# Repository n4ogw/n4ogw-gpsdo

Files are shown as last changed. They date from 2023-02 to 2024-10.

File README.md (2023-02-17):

# N4OGW GPS Disciplined oscillator

This GPSDO is based on the Lars Walenius design posted on eevblog.com:

[https://www.eevblog.com/forum/projects/lars-diy-gpsdo-with-arduino-and-1ns-resolution-tic/](https://www.eevblog.com/forum/projects/lars-diy-gpsdo-with-arduino-and-1ns-resolution-tic/)

The code has been translated from the Arduino to PIC, a
PIC18F27Q84. Unlike the original design external ICs are not used to
divide the 10 MHz input or measure the phase difference between the 1
PPS signal and the input. Instead, PIC Configurable Logic Cell (CLC)
units are used to perform these functions. The only active devices
besides the PIC are an op amp to buffer the PWM output controlling the
OCXO, and an op amp buffer and inverter gate to buffer the sine wave
OCXO output.

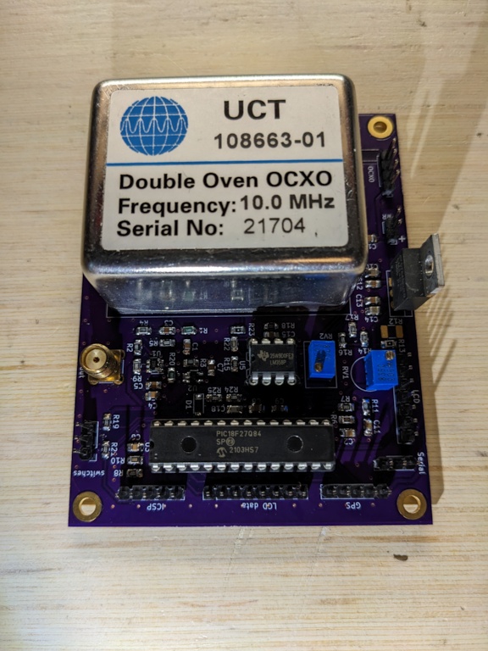
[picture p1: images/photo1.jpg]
GPSDO gpsdo pcb


## Features

* Time interval Counter (TIC) with range of 1000 ns and 0.24 ns/bit
resolution (12 bit ADC)
* 16 bit PWM output for controlling the OCXO
* Direct frequency count of 10 MHz input to monitor frequency
* serial connections for computer and GPS
* LCD display showing UTC time, 6 character grid square, PWM value, lock status, number of satellites, and frequency counter error

---

## Description of hardware

The OCXO is a UCT 108663 with sine wave output. This OCXO requires a
12 V supply. The voltage on the EFC pin for mine is about 5 V when
tuned for 10 MHZ. RV2 is adjusted to first set the frequency of the
OCXO close to 10 MHz. The OCXO is buffered with an ADA4851 op amp and
sent to a 74LVC1G14 inverter before going to the PIC input. The PIC is
a PIC18F27Q84. A PIC18F26Q84 should also work.

 The PIC PWM output is buffered by two op amp stages using an
LM358. The PIC PWM output is set up as a single 16 bit PWM, but a
second pin is available for combining two PWM outputs.  A voltage
regulator on the board generates 5 V for the PIC and the GPS module.
Resistor R17 is not used. The value of R12/R13 depend on whether
current limiting is needed for the LCD backlight; mine did not need
it, so I used a zero ohm jumper. R23 is also a zero ohm jumper.

---

## Description of PIC code

MPLab 6.05; XC8 2.40

### Pins

RA0 - RA7 : (outputs) data for 2x16 LCD in 8 bit mode

RB0 : LCD RS (output)

RB1 : ADC input; reads TIC voltage

RB2 : (input) 10 MHz in

RB3 : (output) TIC to 3.9 k resistor

RB4 : button 1 (input)

RB5 : button 2 (input)

RB6 : ICSP clock

RB7 : ICSP data

RC0 : (input) PPS in

RC1 : LCD E (output)

RC2 : (input) UART2 RX (GPS)

RC3 : (output) UART2 TX (GPS)

RC4 : unused; can be used as second PWM output combined with RC5

RC5 : (output) 16 bit PWM output

RC6 : (output) UART1 TX (computer)

RC7 : (input) UART1 RX  (computer)

### Frequency counter

The PIC Signal Measurement Timer (SMT) is used as a frequency counter
to directly count the 10 MHz input signal. The SMT is used in Counter
mode; the signal comes from SMT1SIGPPS connected to RB2 (10 MHz); the
window comes from SMT1WINPPS connected to RC0 (PPS). Period is set to
0xFFFFFF, pulse width acquisition interrupt is enabled.

In this mode, the interrupt function `SMT1_PW_ACQ_ISR` is called at
every PPS pulse. This function updates the total count and the error
compared to 10 MHz.

### TIC

In the original design, an external IC is used to divide the 10 MHz
down to 1 MHz to drive the TIC. This function is instead done using
PIC CLC gates, one D-type flip-flop (CLC2) configured as divide-by-two
followed by three JK flip-flops (CLC3, CLC5, CLC6) configured as
divide-by-five.  CLCIN2 is connected to RB2, 10 MHz in. The output of
CLC6 is the 1.0 MHz signal.

####CLC2 (divide by 2)

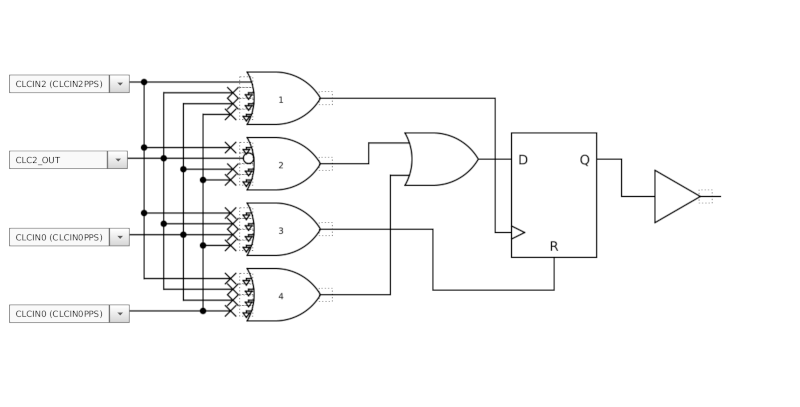
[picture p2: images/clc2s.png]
CLC2 clc2


####CLC3, CLC5, CLC6 (divide by 5)

####CLC3

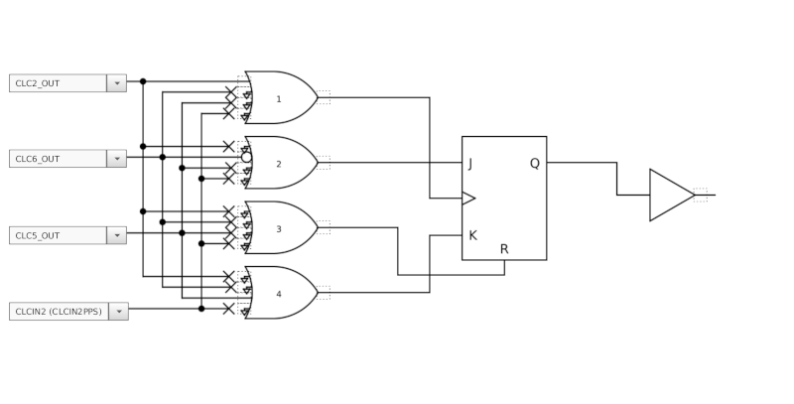
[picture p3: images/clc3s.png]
CLC3 clc3


####CLC5

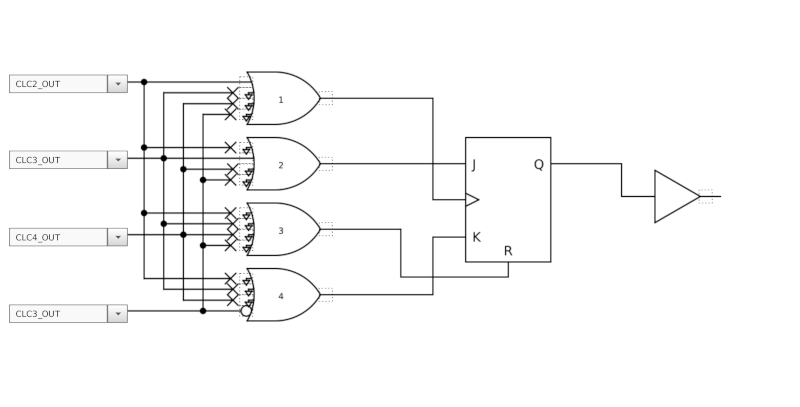
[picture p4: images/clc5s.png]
CLC5 clc5


####CLC6

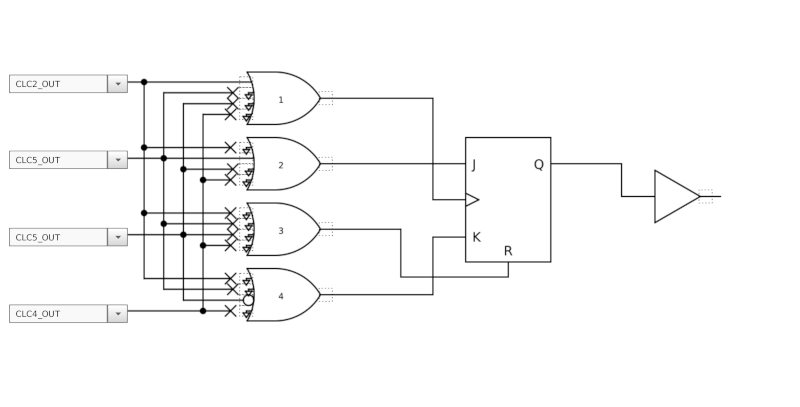
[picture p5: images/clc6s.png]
CLC6 clc6


####CLC1 and CLC7 (2 input D flip-flops with R)

Configured as the phase detector of the TIC. The inputs to CLC1 are
from CLC6 (1.0 MHz) and CLCIN3, which is mapped to RC0 (PPS). The
inputs to CLC7 are also PPS, and the output of CLC1. The output of
CLC7 drives the diode of the TIC circuit (RB3).

CLC1

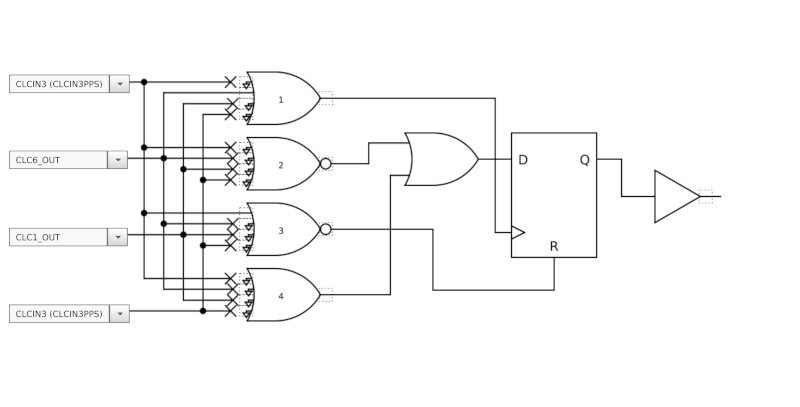
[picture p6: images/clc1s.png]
CLC1 clc1


CLC7

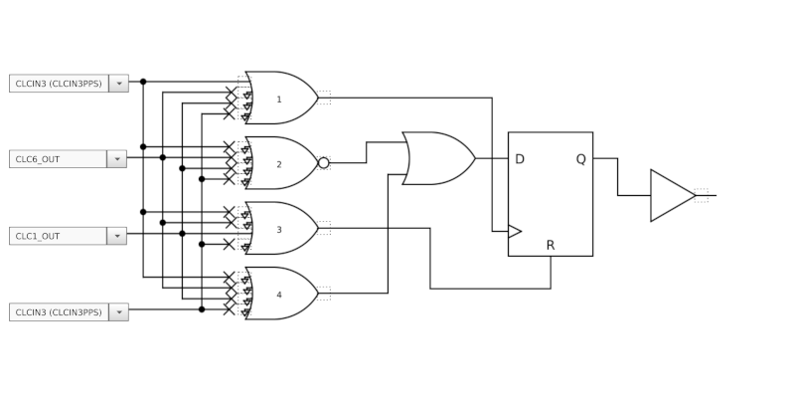
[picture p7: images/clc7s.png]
CLC7 clc7


The reference voltage of the ADC is set to 1.024 V using the FVR
voltage reference. The ADC is set to trigger on the output of
CLC7. The ADC interrupt is enabled; `adcInterrupt()` is the interrupt
function which reads the value of the TIC. With a 12-bit ADC this is
in the range 0-4095.

### Buttons

The two input buttons are debounced using CLC8 and timer 6. CLCIN6 and
CLCIN7 are mapped to the two button pins, RB4 and RB5. Timer 6
is set up in monostable mode with a period of 15 ms, with the output
of CLC8 as the reset source. The timer interrupt function is
`buttonInterrupt()`, which checks to see which button was pressed.

####CLC8

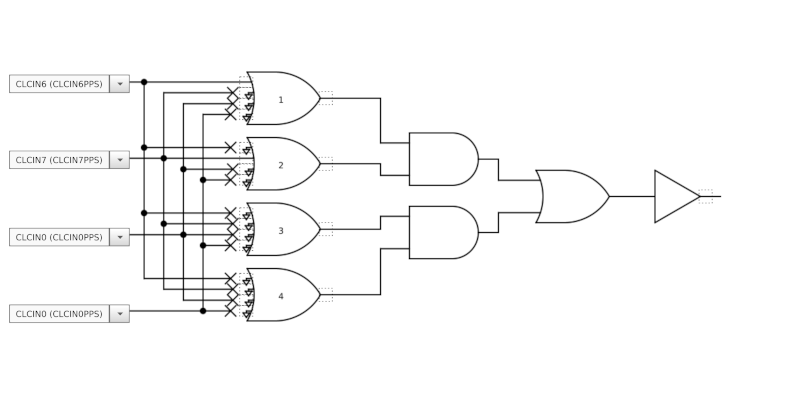
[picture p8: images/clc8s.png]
CLC8 clc8


####2x16 LCD

2x16 LCD library adopted from

[https://github.com/eziya/PIC18F_HD44780](https://github.com/eziya/PIC18F_HD44780)

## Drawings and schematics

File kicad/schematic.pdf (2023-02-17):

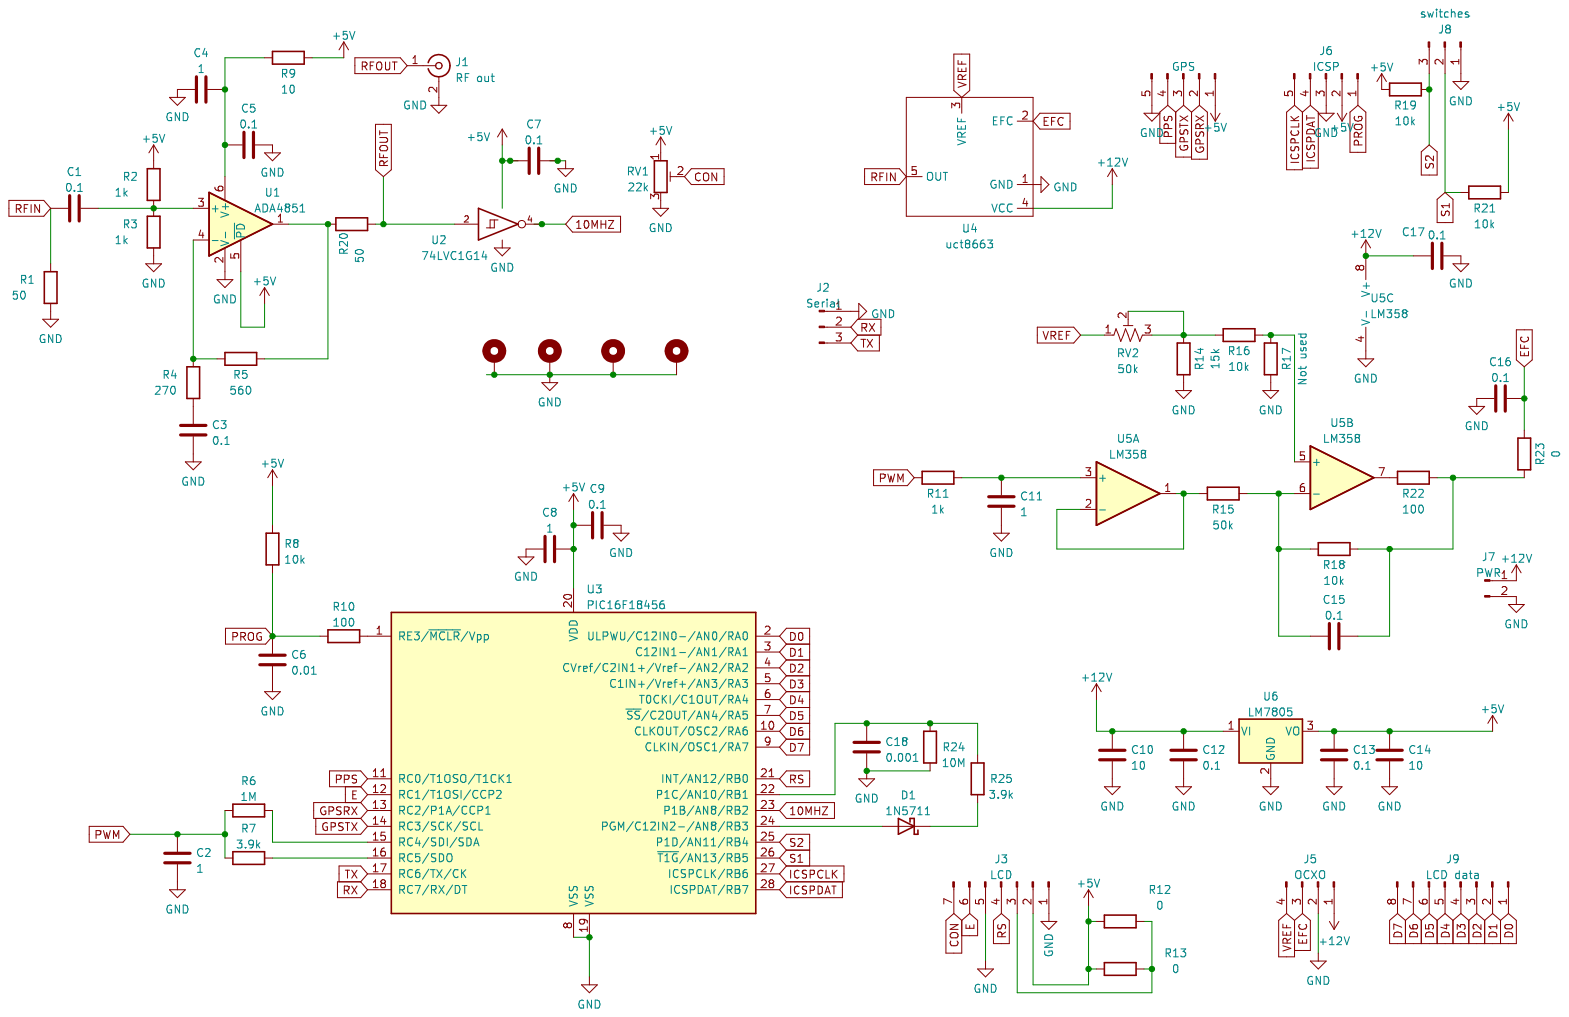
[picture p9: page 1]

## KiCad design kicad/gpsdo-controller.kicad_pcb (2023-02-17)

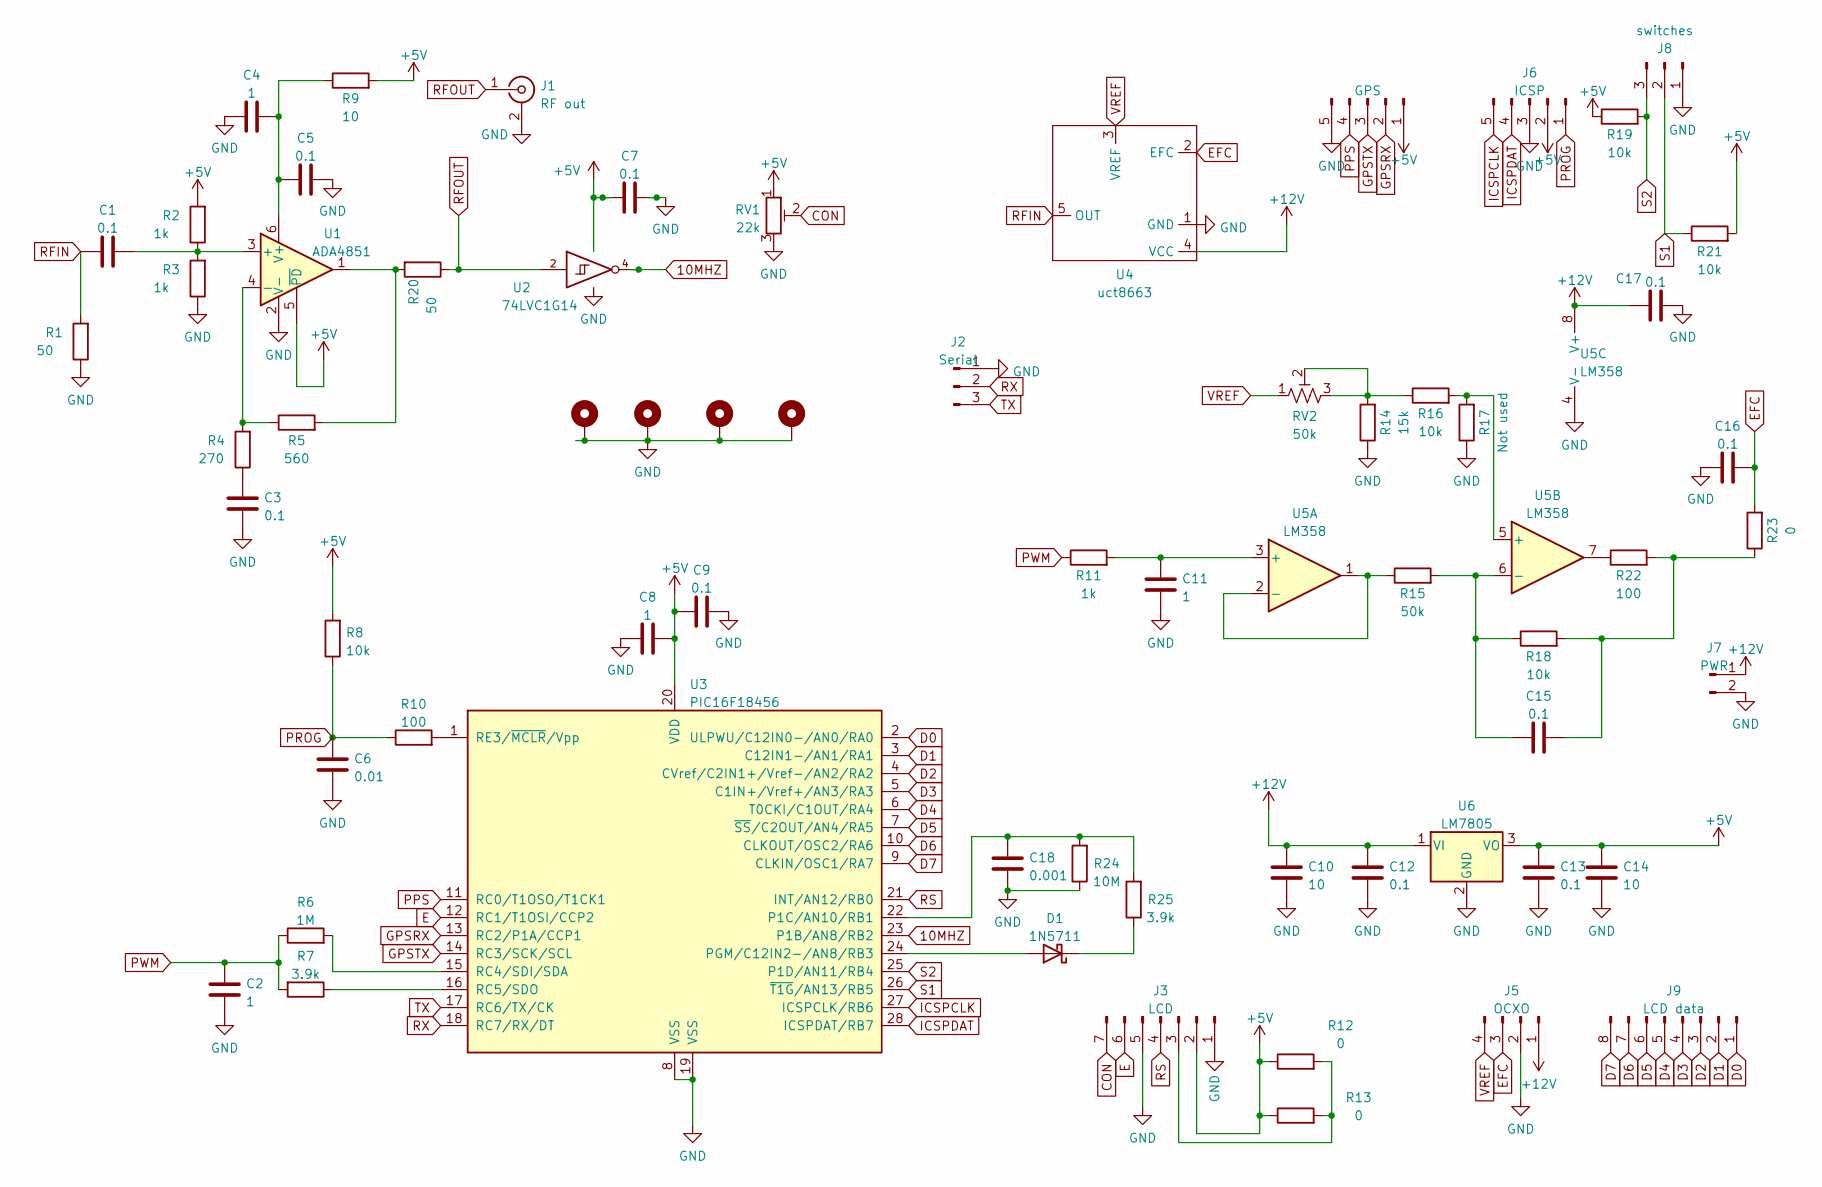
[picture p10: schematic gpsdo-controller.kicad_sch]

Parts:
C1, C3, C5, C7, C9, C12, C13, C15, C16, C17: 0.1; C_0805_2012Metric_Pad1.18x1.45mm_HandSolder
C2, C4, C8, C11: 1; C_0805_2012Metric_Pad1.18x1.45mm_HandSolder
C6: 0.01; C_0805_2012Metric_Pad1.18x1.45mm_HandSolder
C10, C14: 10; C_0805_2012Metric_Pad1.18x1.45mm_HandSolder
C18: 0.001; C_0805_2012Metric_Pad1.18x1.45mm_HandSolder
D1: 1N5711; D_SOD-123
H1, H2, H3, H4: GND; MountingHole_3.2mm_M3_DIN965_Pad
J1: RF out; SMA_Amphenol_901-144_Vertical
J2: Serial; PinHeader_1x03_P2.54mm_Vertical
J3: LCD; PinHeader_1x07_P2.54mm_Vertical
J4: GPS; PinHeader_1x05_P2.54mm_Vertical
J5: OCXO; PinHeader_1x04_P2.54mm_Vertical
J6: ICSP; PinHeader_1x05_P2.54mm_Vertical
J7: PWR; PinHeader_1x02_P2.54mm_Vertical
J8: switches; PinHeader_1x03_P2.54mm_Vertical
J9: LCD data; PinHeader_1x08_P2.54mm_Vertical
R1, R20: 50; R_0805_2012Metric_Pad1.20x1.40mm_HandSolder
R2, R3, R11: 1k; R_0805_2012Metric_Pad1.20x1.40mm_HandSolder
R4: 270; R_0805_2012Metric_Pad1.20x1.40mm_HandSolder
R5: 560; R_0805_2012Metric_Pad1.20x1.40mm_HandSolder
R6: 1M; R_0805_2012Metric_Pad1.20x1.40mm_HandSolder
R7, R25: 3.9k; R_0805_2012Metric_Pad1.20x1.40mm_HandSolder
R8, R16, R18, R19, R21: 10k; R_0805_2012Metric_Pad1.20x1.40mm_HandSolder
R9: 10; R_0805_2012Metric_Pad1.20x1.40mm_HandSolder
R10, R22: 100; R_0805_2012Metric_Pad1.20x1.40mm_HandSolder
R12: 0; R_1210_3225Metric_Pad1.30x2.65mm_HandSolder
R13, R23: 0; R_0805_2012Metric_Pad1.20x1.40mm_HandSolder
R14: 15k; R_0805_2012Metric_Pad1.20x1.40mm_HandSolder
R15: 50k; R_0805_2012Metric_Pad1.20x1.40mm_HandSolder
R17: Not used; R_0805_2012Metric_Pad1.20x1.40mm_HandSolder
R24: 10M; R_0805_2012Metric_Pad1.20x1.40mm_HandSolder
RV1: 22k; Potentiometer_Vishay_T7-YA_Single_Vertical
RV2: 50k; Potentiometer_Bourns_3299Y_Vertical
U1: ADA4851; SOT-23-6
U2: 74LVC1G14; SOT-353_SC-70-5_Handsoldering
U3: PIC16F18456; DIP-28_W7.62mm
U4: uct8663
U5: LM358; DIP-8_W7.62mm
U6: LM7805; TO-220-3_Vertical

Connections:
10MHZ: U2.4, U3.23 (P1B/AN8/RB2)
+5V: C7.1, C8.2, C9.1, C13.2, C14.2, J3.2, J4.1, J6.2, R2.2, R8.2, R9.2, R12.1, R13.1, R19.1, R21.2, RV1.1, U1.5 (~PD), U2.5 (VCC), U3.20 (VDD), U6.3 (VO)
+12V: C10.2, C12.2, C17.1, J5.1, J7.1, U4.4 (VCC), U5.8 (V+), U6.1 (VI)
CON: J3.7, RV1.2
D0: J9.1, U3.2 (ULPWU/C12IN0-/AN0/RA0)
D1: J9.2, U3.3 (C12IN1-/AN1/RA1)
D2: J9.3, U3.4 (CVref/C2IN1+/Vref-/AN2/RA2)
D3: J9.4, U3.5 (C1IN+/Vref+/AN3/RA3)
D4: J9.5, U3.6 (T0CKI/C1OUT/RA4)
D5: J9.6, U3.7 (~SS/C2OUT/AN4/RA5)
D6: J9.7, U3.10 (CLKOUT/OSC2/RA6)
D7: J9.8, U3.9 (CLKIN/OSC1/RA7)
E: J3.6, U3.12 (RC1/T1OSI/CCP2)
EFC: C16.1, J5.3, R23.2, U4.2 (EFC)
GND: C2.1, C3.1, C4.1, C5.2, C6.1, C7.2, C8.1, C9.2, C10.1, C11.1, C12.1, C13.1, C14.1, C16.2, C17.2, C18.1, H1.1, H2.1, H3.1, H4.1, J1.2 (Ext), J2.1, J3.1, J3.5, J4.5, J5.2, J6.3, J7.2, J8.1, R1.1, R3.1, R14.1, R17.1, R24.1, RV1.3, U1.2 (V-), U2.3 (GND), U3.8 (VSS), U3.19 (VSS), U4.1 (GND), U5.4 (V-), U6.2 (GND)
GPSRX: J4.2, U3.13 (RC2/P1A/CCP1)
GPSTX: J4.3, U3.14 (RC3/SCK/SCL)
ICSPCLK: J6.5, U3.27 (ICSPCLK/RB6)
ICSPDAT: J6.4, U3.28 (ICSPDAT/RB7)
unnamed: C1.2, R2.1, R3.2, U1.3 (+)
unnamed: C3.2, R4.1
unnamed: C4.2, C5.1, R9.1, U1.6 (V+)
unnamed: C11.2, R11.2, U5.3 (+)
unnamed: C15.1, R15.2, R18.1, U5.6 (-)
unnamed: C15.2, R18.2, R22.2, R23.1
unnamed: C18.2, R24.2, R25.2, U3.22 (P1C/AN10/RB1)
unnamed: D1.1 (K), R25.1
unnamed: D1.2 (A), U3.24 (PGM/C12IN2-/AN8/RB3)
unnamed: J3.3, R12.2, R13.2
unnamed: R4.2, R5.1, U1.4 (-)
unnamed: R6.2, U3.15 (RC4/SDI/SDA)
unnamed: R7.1, U3.16 (RC5/SDO)
unnamed: R10.2, U3.1 (RE3/~MCLR/Vpp)
unnamed: R14.2, R16.1, RV2.2, RV2.3
unnamed: R15.1, U5.1, U5.2 (-)
unnamed: R16.2, R17.2, U5.5 (+)
unnamed: R5.2, R20.2, U1.1
unnamed: R22.1, U5.7
PPS: J4.4, U3.11 (RC0/T1OSO/T1CK1)
PROG: C6.2, J6.1, R8.1, R10.1
PWM: C2.2, R6.1, R7.2, R11.1
RFIN: C1.1, R1.2, U4.5 (OUT)
RFOUT: J1.1 (In), R20.1, U2.2
RS: J3.4, U3.21 (INT/AN12/RB0)
RX: J2.2, U3.18 (RC7/RX/DT)
S1: J8.2, R21.1, U3.26 (~T1G/AN13/RB5)
S2: J8.3, R19.2, U3.25 (P1D/AN11/RB4)
TX: J2.3, U3.17 (RC6/TX/CK)
VREF: J5.4, RV2.1, U4.3 (VREF)

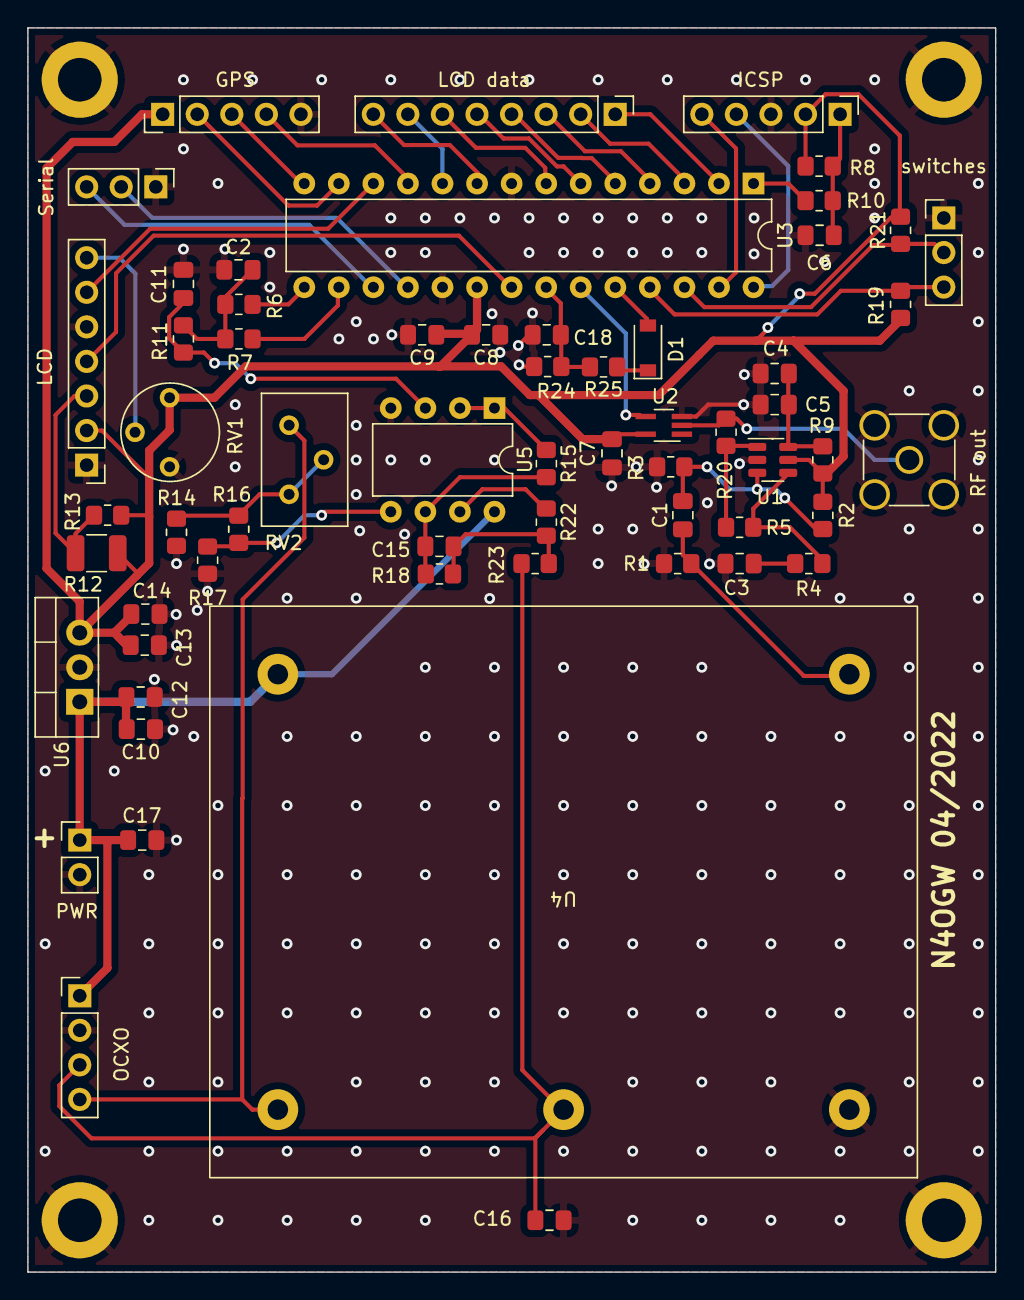
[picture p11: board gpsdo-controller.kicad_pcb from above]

Board: 2 copper layers, 71.1 x 91.4 mm, 65 parts (0 on the bottom side), 49 nets.

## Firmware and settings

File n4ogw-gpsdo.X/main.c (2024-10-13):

/*
 GPSDO controller based on "Lars GPSDO" design using PIC18F27Q84

 R. Torsten Clay N4OGW
  
 for board version 2
 05/20/2023

  1. Counts 10 MHz directly using PIC SMT
  2. Divides 10 MHz down to 1 MHz; measures phase difference between 1 MHz and
     GPS PPS signal

  Frequency division and phase difference measurement are done using PIC
  CLC gates instead of by external hardware:
 
  -two CLC D flip-flops are used (CLC1 and CLC7) for the phase detector
  -CLC2, CLC3, CLC5, CLC6 are configured as a divide-by-10 counter
      -> these together create a 1 MHz signal from the OCXO (duty
      cycle is not 50%)
  -CLC8 and timer6 are used to de-bounce buttons
  -SMT is used to count 10 MHz directly (24 bit counter), gated by PPS
  -16 bit PWM generated directly instead of combining two 8-bit PWMs
 
  Pin connections:
 
  RA0 - RA7 : outputs; data for 2x16 LCD in 8 bit mode
  RB0 : LCD RS
  RB1 : ADC input; reads TIC voltage
  RB2 : 10 MHz in
  RB3 : TIC output; to 3.9 k resistor
  RB4 : button 1
  RB5 : button 2
  RB6 : ICSP clock
  RB7 : ICSP data
  RC0 : pps in
  RC1 : LCD E
  RC2 : uart2 rx (gps)
  RC3 : uart2 tx (gps)
  RC4 unused : can be 2nd pwm output
  RC5 : 16 bit PWM out
  RC6 : uart1 tx (computer)
  RC7 : uart1 rx (computer)
 */

// suppress MCC "function never called" messages
#pragma warning disable 520
#pragma warning disable 2053

#include <stdio.h>
#include <stdlib.h>
#include <stdbool.h>
#include "defines.h"
#include "mcc_generated_files/pin_manager.h"
#include "mcc_generated_files/mcc.h"
#include "mcc_generated_files/pwm1_16bit.h"
#include "xlcd.h"

void adcInterrupt();
void buttonInterrupt(void);
void button2Func(void);
void calculation(void);
void checkButtons(void);
void counterSetup(void);
void counterUpdate(void);
void getCommand(void);
void gpsConfig(void);
void gpsExtraOff(void);
void gpsExtraOn(void);
void gpsParse(void);
void gpsRead(void);
inline uint8_t highByte(uint16_t x);
inline uint8_t lowByte(uint16_t x);
void lcdSetup(void);
void lcdUpdate(void);
long parseInt(void);
void printDataToSerial(void);
void printHeader1_ToSerial(void);
void printHeader2_ToSerial(void);
void printHeader3_ToSerial(void);
void setup(void);
void setScreen(screenType newScreen);

uint16_t warmUpTime = 300; // 300 gives five minutes hold during eg OCXO or Rb warmup. Set to eg 3 for VCTCXO
int32_t dacValueOut = 32768; // 16bit PWM-DAC setvalue=startvalue Max 65535 (if nothing stored in the EEPROM)
int32_t dacValue; // this is also same as "DACvalueOld" Note: is "0-65535" * timeconst

volatile uint16_t TIC_Value; // analog read 0  - time value. About 0.25ns per bit with 3.9kohm+1nF
uint16_t TIC_ValueCopy;
uint16_t TIC_ValueOld; // old not filtered TIC_value

int32_t TIC_ValueFiltered; // pre-filtered TIC value
int32_t TIC_ValueFilteredOld; // old filtered value
int32_t TIC_ValueFilteredForPPS_lock; // pre-filtered value just for PPS lock
const uint8_t lockFilterConst = 16;

volatile uint32_t timer1CounterValue; // counts 10 MHz clock directly
uint32_t timer1CounterValueOld;

long timer_us; // timer1 value in microseconds offset from 1pps
long timer_us_old; // used for diff_ns
// timer_us is calculated, but not used for dac correction in this
// version of code
long diff_ns; // difference between old and new TIC_Value
long diff_ns_ForPPS_lock; // pre-filtered value just for PPS lock

long timeConst = 128; // Time constant in seconds
long timeConstOld = 128; // old Time constant
int filterDiv = 2; // filterConst = timeConst / filterDiv
long filterConst = 64; // pre-filter time const in secs (TIC-filtering)
long filterConstOld = 64; // old Filter time constant

float I_term; //for PI-loop
float P_term;
long I_term_long;
float I_term_remain;

long gain = 275;

// Arduino TIC calculation:
// VCO freq DAC bits per TIC bit (65536/VCOrange in ppb (eg. with 1nS/bit and 100ppb DACrange gives gain=655))
//
// PIC TIC calculation:
//     12 bit ADC, 1 MHz : 1000ns/4096 = 0.24 ns/bit, so now gain 
//     is 0.24*65536/VCO_ppb

float damping = 3.0; // Damping in loop

unsigned long time; //seconds since start
unsigned long timeOld; //last seconds since start
volatile bool ADCFlag = false; // set true every time ADC reads TIC
volatile bool SMTFlag = false;

#ifdef VENUS838T
extern uint8_t venusElevMask;
extern uint8_t venusMode;
extern uint8_t venusSurveyCnt[8];
extern void setVenusElevMask(uint8_t x);
#endif

float quantErr;
bool quantErrFlag;      // correct for gps time quantization error if available
int lockPPSlimit = 200; // if TIC filtered for PPS within +- this for lockPSfactor * timeConst = PPSlocked
                        // ~ 100 per 1000 of ADC range
int lockPPSfactor = 5;  // see above
unsigned long lockPPScounter; // counter for PPSlocked
bool PPSlocked; // prints 0 or 1

int i; // counter for 300secs before storing temp and dac readings average
int j; // counter for stored 300sec readings
int k; // counter for stored 3hour readings
unsigned int StoreTIC_A[NSTORE]; //300sec storage
unsigned int StoreDAC_A[NSTORE];
long sumTIC;
long sumTIC2;
long sumTemp;
long sumTemp2;
unsigned long sumDAC;
unsigned long sumDAC2;
unsigned int totalTime3h; // counter for power-up time updated every third hour

unsigned int ID_Number;

bool lessInfoDisplayed;
bool nsDisplayedDecimals;

SerialModes serialMode = on;
unsigned int holdValue; //DAC value for Hold mode
Modes opMode; //operating mode
Modes newMode; // used to reset timer_us when run is set and at to many missing PPS

// for TIC linearization
// RTC: best parameters found using a PicDiv
float TICmin = 60.0;
float TICmax = 4036.0;
long TIC_Offset = 2048; // ADC value for Reference time. This is chosen in the middle point of
// the ADC range.
float x3 = 0.03;
float x2 = 0.08;
float x1;
float TIC_Scaled;
float TIC_ValueCorr;
float TIC_ValueCorrOld;
float TIC_ValueCorrOffset;

const int dacSign = -1; // sign of OCXO EFC correction. +1 in original code, -1 if tuning is inverted
volatile uint16_t cnt; // counts measurements 65535 is max
volatile uint32_t elapsed;
volatile int totalErr; // total error count
uint16_t nCnt = 1000; // frequency counter gate time in seconds
int lostPPSCount;
const uint8_t nScreen = 5;
screenType screen;
uint8_t gpsTime[9]; // latest time from GPS
char errStr[8]; // displayed frequency error
char pwmStr[6]; // displayed pwm setting
uint8_t gpsSentence[256]; // one GPS NMEA line
uint8_t grid[7]; // 6 character grid square from GPS
uint8_t nsat[3]; // number of satellites received by GPS
uint8_t gpsCnt; // counts up to 256 to read one GPS line
uint8_t gpsCheckCnt; // counter for gps checksum
uint16_t gridCnt; // counter to periodically update grid 
const uint16_t gridFreq = 3000; // time in seconds to recheck grid square

volatile uint8_t button1State; // button 1. 0=not pushed 1=pushed
volatile uint8_t button2State; // button 2. 0=not pushed 1=pushed

void main(void) {
    // Initialize the device
    SYSTEM_Initialize();

    ADC_SetADIInterruptHandler(adcInterrupt);
    // If using interrupts in PIC18 High/Low Priority Mode you need to enable the Global High and Low Interrupts
    // If using interrupts in PIC Mid-Range Compatibility Mode you need to enable the Global Interrupts
    // Use the following macros to:

    // Enable the Global Interrupts
    INTERRUPT_GlobalInterruptEnable();

    // Disable the Global Interrupts
    //INTERRUPT_GlobalInterruptDisable();

    __delay_ms(1000);
    setup();
    counterSetup();
    lcdSetup();
    PWM1_16BIT_Enable();
    SMT1_DataAcquisitionEnable();
    
    INTERRUPT_GlobalInterruptEnable();
    
    while (1) {
        if (SMTFlag == true) {
            if (cnt >= nCnt) {
                counterUpdate();
            }
            SMTFlag = false;
        }
        if (ADCFlag == true) {
            calculation();
            ADCFlag = false;
            if (serialMode == on) printDataToSerial();
            lcdUpdate();
        }
        if (serialMode == on || serialMode == gps) getCommand();
        gpsRead();
        checkButtons();
    }
}

/* 
 Interrupt triggered when ADC conversion of TIC value is
 ready. This should always come after the SMT timer
 interrupt
 
 MCC generated function clears the interrupt bit
 */
void adcInterrupt() {
    TIC_Value = (uint16_t)((ADRESH << 8) + ADRESL);
    ADCFlag = true;
}

/*
   Interrupt triggered when SMT finishes measurement
   this is triggered every PPS pulse
 */
void SMT1_PW_ACQ_ISR(void) {
    timer1CounterValueOld = timer1CounterValue;
    timer1CounterValue = SMT1CPW;

    // handle counter rollover (SMT is 24 bit counter, value is held as
    // 32-bit unsigned)
    elapsed = timer1CounterValue - timer1CounterValueOld;
    if (timer1CounterValue < timer1CounterValueOld) {
      elapsed += 0xff000000;
    }
   
    totalErr += (elapsed - FREQ);
    cnt++;

    SMTFlag = true;
    PIR1bits.SMT1PWAIF = 0;
}

/*
  Update frequency counter. This does a simple count
  of the frequency over nCnt seconds.
 */
void counterUpdate(void) {

    // first count is invalid since timer1CounterValueOld undefined
    if (time < (warmUpTime + nCnt)) {
        cnt = 0;
        totalErr = 0;
        return;
    }
    // average error in Hz
    float err = totalErr / (float) nCnt;

    // construct frequency error string
    switch (nCnt) {
        case 10:
            sprintf(errStr, "%3.1f    ", err);
            break;
        case 100:
            sprintf(errStr, "%4.2f   ", err);
            break;
        case 1000:
            sprintf(errStr, "%5.3f  ", err);
            break;
        default:
            sprintf(errStr, "%6.4f ", err);
            break;
    }
    // replace leading zero with sign or blank
    // for zero
    if (totalErr == 0) {
        errStr[0] = 0x20; //' '
    } else if (totalErr > 0) {
        errStr[0] = 0x2b; //'+'
    } else {
        errStr[0] = 0x2d; //'-'
    }
    if (screen == home) {
        CLCD_SetPos(0, 0);
        CLCD_PutS((char *) errStr);
    }
    if (serialMode == on) printf("FREQ COUNTER ERROR = %f Hz\r\n", err);
    cnt = 0;
    totalErr = 0;

}

void calculation(void) {
    if ((timer1CounterValue - timer1CounterValueOld) == 0) {
        if (serialMode == on) printf("No PPS\r\n");
        lostPPSCount++;
        if (lostPPSCount > 20) {
            newMode = run;
        }
        if (lostPPSCount > 200) {
            lockPPScounter = 0;
        }

    } else {
        lostPPSCount = 0;
    }

    // TIC linearization
    TIC_ValueCopy = TIC_Value;
    x1 = (float) 1.0 - x3 - x2;
    TIC_Scaled = ((float) TIC_Offset - TICmin) / (TICmax - TICmin)*1000; // Scaling for TIC_Offset
    TIC_ValueCorrOffset = TIC_Scaled * x1 + TIC_Scaled * TIC_Scaled * x2 / (float) 1000.0 +
            TIC_Scaled * TIC_Scaled * TIC_Scaled * x3 / (float) 1000000.0;

    TIC_Scaled = ((float) TIC_ValueCopy - TICmin) / (TICmax - TICmin)*1000; // Scaling for TIC_Value
    TIC_ValueCorr = TIC_Scaled * x1 + TIC_Scaled * TIC_Scaled * x2 / (float) 1000.0 +
            TIC_Scaled * TIC_Scaled * TIC_Scaled * x3 / (float) 1000000.0;

    if (quantErrFlag) TIC_ValueCorr += quantErr;

    // timer_us
    // dt is in units of 10^-7 = 0.1 microseconds = 100 ns
    long dt = elapsed - FREQ;

    // timer_us is in microseconds
    if (quantErrFlag) {
        timer_us = timer_us - (dt * 100
                + (TIC_ValueCopy + (int) quantErr - TIC_ValueOld)*1000 / 4096) / 1000;
    } else {
        timer_us = timer_us - (dt * 100
                + (TIC_ValueCopy - TIC_ValueOld)*1000 / 4096) / 1000;
    }

    if (newMode == run) {
        // reset timer_us if change from hold mode to run mode
        timer_us = 0;
        timer_us_old = 0;
        TIC_ValueFilteredOld = TIC_Offset * filterConst;
        newMode = hold;
    }

    // reset in the beginning and end of warmup 
    if (time < 3 || (time > (warmUpTime - 1) && time < (warmUpTime + 1))) {
        timer_us = 0;
    }

    if ((labs(timer_us) - 2) > timeConst * 65536 / gain / 1000 && opMode == run && time > warmUpTime) {
        timer_us = 0;
        timer_us_old = 0;
        TIC_ValueFilteredOld = TIC_Offset * filterConst;
    }

    // Diff_ns
    if (TIC_ValueCorr > TIC_ValueCorrOld) {
        // = Frequency in ppb if updated every second! Note: TIC linearized
        diff_ns = (timer_us - timer_us_old)*1000 +
                (long) (TIC_ValueCorr - TIC_ValueCorrOld + 0.5);
    } else {
        diff_ns = (timer_us - timer_us_old)*1000 +
                (long) (TIC_ValueCorr - TIC_ValueCorrOld - 0.5);
    }

    // time - seconds since start
    if ((timer1CounterValue - timer1CounterValueOld) != 0) time++;

    ////// PPS locked

    // Low Pass Filter of TIC_Value for PPS lock  
    // /16 is used as 500ns error and /16 is about 30ns that seems reasonable
    TIC_ValueFilteredForPPS_lock = TIC_ValueFilteredForPPS_lock + (TIC_ValueCopy * lockFilterConst - TIC_ValueFilteredForPPS_lock) / lockFilterConst;

    // Low Pass Filter of diff_ns for PPS lock                                                                             
    diff_ns_ForPPS_lock = diff_ns_ForPPS_lock + (diff_ns * lockFilterConst - diff_ns_ForPPS_lock) / lockFilterConst;

    lockPPScounter = lockPPScounter + 1;
    if (labs(TIC_ValueFilteredForPPS_lock / lockFilterConst - TIC_Offset) > lockPPSlimit) {
        lockPPScounter = 0;
    }
    // if freq more than 20ppb wrong (had to add this to avoid certain combinations not covered by above)
    if (labs(diff_ns_ForPPS_lock / lockFilterConst) > 20) {
        lockPPScounter = 0;
    }
    
    if (lockPPScounter > timeConst * lockPPSfactor) {
        PPSlocked = 1;
        if (screen == home) {
            CLCD_SetPos(0, 12);
            CLCD_PutS("L");
        }
    } else {
        PPSlocked = 0;
        if (screen == home) {
            CLCD_SetPos(0, 12);
            if (time > warmUpTime) {
                CLCD_PutS(" ");
            } else {
                CLCD_PutS("W");
            }
        }
    }
    if (screen == home) {
        switch (time % 2) {
            case 0:
                CLCD_SetPos(0, 11);
                CLCD_PutS("|");
                break;
            case 1:
                CLCD_SetPos(0, 11);
                CLCD_PutS("-");
                break;
        }
    }
     
    // set filter constant
    filterConst = timeConst / filterDiv;
    if (filterConst < 1) {
        filterConst = 1;
    } else if (filterConst > 1024) {
        filterConst = 1024;
    }
    if (PPSlocked == 0 || opMode == hold) filterConst = 1;

    // recalculation of value  
    if (timeConst != timeConstOld) {
        dacValue = dacValue / timeConstOld * timeConst;
    }

    if (filterConst != filterConstOld) {
        TIC_ValueFilteredOld = TIC_ValueFilteredOld / filterConstOld * filterConst;
        TIC_ValueFiltered = TIC_ValueFiltered / filterConstOld * filterConst;
    }

    // Low Pass Filter for TICvalue (Phase Error)
    // Remember that TIC_ValueFiltered is multiplied by filterConst

    // Don´t update if outlier. Accepts diff_ns less than same ns as vco range in ppb + 200ns
    // First check to avoid overflow in next calculation (also max VCO range is about 6500ns/s)

    // RTC changes: ignore large TIC changes if locked.
    if (abs(diff_ns < 260))
        // if (PPSlocked==0 || (PPSlocked==1 && diff_ns < 260))
    {
        if (labs(diff_ns * gain) < (65535 + 200 * gain)) {
            if (quantErrFlag) {
                TIC_ValueFiltered = TIC_ValueFiltered +
                        ((timer_us * 1000 +
                        TIC_ValueCopy + (int) quantErr) * filterConst - TIC_ValueFiltered + (filterConst / 2)) / filterConst;
            } else {
                TIC_ValueFiltered = TIC_ValueFiltered +
                        ((timer_us * 1000 +
                        TIC_ValueCopy) * filterConst - TIC_ValueFiltered + (filterConst / 2)) / filterConst;
            }
        }
    }

    // Don't change DAC-value during warm-up time or if in hold mode
    if (time > (warmUpTime + 1) && opMode == run) {
        ////// PI-loop ///////
        // remember /timeConst is done before dacValue is sent out
        P_term = (TIC_ValueFiltered - TIC_Offset * filterConst) / (float) (filterConst) * gain;

        I_term = P_term / damping / (float) (timeConst) + I_term_remain;
        I_term_long = (long) (I_term);
        I_term_remain = I_term - I_term_long;
        dacValue += dacSign * I_term_long;
        dacValueOut = dacValue + dacSign * P_term;
    } else {
        dacValueOut = dacValue; // No change
    }
    // Check that dacvalue is within limits
    if (dacValue < 0) {
        dacValue = 0;
    }
    if (dacValue > (65535 * timeConst)) {
        dacValue = (65535 * timeConst);
    }

    dacValueOut /= timeConst; // PWM-DAC value
    if (dacValueOut < 0) {
        dacValueOut = 0;
    }
    if (dacValueOut > 65535) {
        dacValueOut = 65535;
    }

    // manual set of dacvalue if in hold and not 0, if zero hold old value
    if (holdValue > 0 && opMode == hold) {
        dacValueOut = holdValue;
    }

    // Set 16bit DAC
    PWM1_16BIT_SetSlice1Output1DutyCycleRegister((uint16_t) dacValueOut);
    PWM1_16BIT_LoadBufferRegisters();

    sprintf(pwmStr, "%4x", (uint16_t) dacValueOut);
    if (screen == home) {
        CLCD_SetPos(0, 7);
        CLCD_PutS((char*) pwmStr);
    }

    //Storage of average readings that is later printed
    sumTIC = sumTIC + (TIC_ValueCopy * 10);
    sumDAC = sumDAC + dacValueOut;
    i = i + 1;
    if (i == 300) // 300sec
    {
        if (opMode == run) {
            StoreTIC_A[j] = sumTIC / i;
        } else {
            StoreTIC_A[j] = TIC_ValueCopy;
        }
        sumTIC2 = sumTIC2 + sumTIC / i;
        sumTIC = 0;
        if (opMode == run) {
            StoreDAC_A[j] = sumDAC / i;
        } else {
            StoreDAC_A[j] = ((FREQ - 1) - timer1CounterValue);
        }

        sumDAC2 = sumDAC2 + sumDAC / i;
        sumDAC = 0;
        i = 0;
        j = j + 1;
        if (j % 36 == 0) // store every 36 x 300sec (3 hours)
        {
            sumTIC2 = sumTIC2 / 36;
            if (opMode == run) {
                DATAEE_WriteByte((uint16_t) k, highByte((uint16_t) sumTIC2));
                DATAEE_WriteByte((uint16_t) (k + NSTORE), lowByte((uint16_t) sumTIC2));
            } else {
                DATAEE_WriteByte((uint16_t) k, highByte((uint16_t) TIC_ValueCopy));
                DATAEE_WriteByte((uint16_t) (k + NSTORE), lowByte((uint16_t) TIC_ValueCopy));
            }
            sumTIC2 = 0;

            sumDAC2 = sumDAC2 / 36;

            if (opMode == run) {
                DATAEE_WriteByte((uint16_t) (k + 2*NSTORE), highByte((uint16_t) sumDAC2));
                DATAEE_WriteByte((uint16_t) (k + 3*NSTORE), lowByte((uint16_t) sumDAC2));
            } else {
                DATAEE_WriteByte((uint16_t) (k + 2*NSTORE), highByte((uint16_t) (((FREQ - 1) - timer1CounterValue))));
                DATAEE_WriteByte((uint16_t) (k + 3*NSTORE), lowByte((uint16_t) ((FREQ - 1) - timer1CounterValue)));
            }

            if (opMode == run && lockPPScounter > 10800) {
                DATAEE_WriteByte(1017, highByte((uint16_t) sumDAC2));
                DATAEE_WriteByte(1018, lowByte((uint16_t) sumDAC2));
            }

            sumDAC2 = 0;

            if (j == NSTORE) // 144 x 300sec (12 hours)
            {
                j = 0;
            }
            k = k + 1;
            if (k == NSTORE) // 144 x 10800sec (18 days)
            {
                k = 0;
            }
            DATAEE_WriteByte(1023, (uint8_t) k); // store present k (index of 3 hour average, used in setup)

            totalTime3h = totalTime3h + 1;
            DATAEE_WriteByte(993, highByte(totalTime3h));
            DATAEE_WriteByte(994, lowByte(totalTime3h));
        }
    }

    // storage of old parameters
    TIC_ValueOld = TIC_ValueCopy;
    if (quantErrFlag) TIC_ValueOld += (int) quantErr;
    TIC_ValueCorrOld = TIC_ValueCorr;
    timer_us_old = timer_us;
    timeConstOld = timeConst;
    filterConstOld = filterConst;
    timeOld = time;
    TIC_ValueFilteredOld = TIC_ValueFiltered;
}
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

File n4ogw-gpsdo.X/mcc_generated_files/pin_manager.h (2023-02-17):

/**
  @Generated Pin Manager Header File

  @Company:
    Microchip Technology Inc.

  @File Name:
    pin_manager.h

  @Summary:
    This is the Pin Manager file generated using PIC10 / PIC12 / PIC16 / PIC18 MCUs

  @Description
    This header file provides APIs for driver for .
    Generation Information :
        Product Revision  :  PIC10 / PIC12 / PIC16 / PIC18 MCUs - 1.81.8
        Device            :  PIC18F27Q84
        Driver Version    :  2.11
    The generated drivers are tested against the following:
        Compiler          :  XC8 2.36 and above
        MPLAB 	          :  MPLAB X 6.00	
*/

/*
    (c) 2018 Microchip Technology Inc. and its subsidiaries. 
    
    Subject to your compliance with these terms, you may use Microchip software and any 
    derivatives exclusively with Microchip products. It is your responsibility to comply with third party 
    license terms applicable to your use of third party software (including open source software) that 
    may accompany Microchip software.
    
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
    IN NO EVENT WILL MICROCHIP BE LIABLE FOR ANY INDIRECT, SPECIAL, PUNITIVE, 
    INCIDENTAL OR CONSEQUENTIAL LOSS, DAMAGE, COST OR EXPENSE OF ANY KIND 
    WHATSOEVER RELATED TO THE SOFTWARE, HOWEVER CAUSED, EVEN IF MICROCHIP 
    HAS BEEN ADVISED OF THE POSSIBILITY OR THE DAMAGES ARE FORESEEABLE. TO 
    THE FULLEST EXTENT ALLOWED BY LAW, MICROCHIP'S TOTAL LIABILITY ON ALL 
    CLAIMS IN ANY WAY RELATED TO THIS SOFTWARE WILL NOT EXCEED THE AMOUNT 
    OF FEES, IF ANY, THAT YOU HAVE PAID DIRECTLY TO MICROCHIP FOR THIS 
    SOFTWARE.
*/

#ifndef PIN_MANAGER_H
#define PIN_MANAGER_H

/**
  Section: Included Files
*/

#include <xc.h>

#define INPUT   1
#define OUTPUT  0

#define HIGH    1
#define LOW     0

#define ANALOG      1
#define DIGITAL     0

#define PULL_UP_ENABLED      1
#define PULL_UP_DISABLED     0

// get/set RA0 procedures
#define RA0_SetHigh()            do { LATAbits.LATA0 = 1; } while(0)
#define RA0_SetLow()             do { LATAbits.LATA0 = 0; } while(0)
#define RA0_Toggle()             do { LATAbits.LATA0 = ~LATAbits.LATA0; } while(0)
#define RA0_GetValue()              PORTAbits.RA0
#define RA0_SetDigitalInput()    do { TRISAbits.TRISA0 = 1; } while(0)
#define RA0_SetDigitalOutput()   do { TRISAbits.TRISA0 = 0; } while(0)
#define RA0_SetPullup()             do { WPUAbits.WPUA0 = 1; } while(0)
#define RA0_ResetPullup()           do { WPUAbits.WPUA0 = 0; } while(0)
#define RA0_SetAnalogMode()         do { ANSELAbits.ANSELA0 = 1; } while(0)
#define RA0_SetDigitalMode()        do { ANSELAbits.ANSELA0 = 0; } while(0)

// get/set channel_ANB1 aliases
#define channel_ANB1_TRIS                 TRISBbits.TRISB1
#define channel_ANB1_LAT                  LATBbits.LATB1
#define channel_ANB1_PORT                 PORTBbits.RB1
#define channel_ANB1_WPU                  WPUBbits.WPUB1
#define channel_ANB1_OD                   ODCONBbits.ODCB1
#define channel_ANB1_ANS                  ANSELBbits.ANSELB1
#define channel_ANB1_SetHigh()            do { LATBbits.LATB1 = 1; } while(0)
#define channel_ANB1_SetLow()             do { LATBbits.LATB1 = 0; } while(0)
#define channel_ANB1_Toggle()             do { LATBbits.LATB1 = ~LATBbits.LATB1; } while(0)
#define channel_ANB1_GetValue()           PORTBbits.RB1
#define channel_ANB1_SetDigitalInput()    do { TRISBbits.TRISB1 = 1; } while(0)
#define channel_ANB1_SetDigitalOutput()   do { TRISBbits.TRISB1 = 0; } while(0)
#define channel_ANB1_SetPullup()          do { WPUBbits.WPUB1 = 1; } while(0)
#define channel_ANB1_ResetPullup()        do { WPUBbits.WPUB1 = 0; } while(0)
#define channel_ANB1_SetPushPull()        do { ODCONBbits.ODCB1 = 0; } while(0)
#define channel_ANB1_SetOpenDrain()       do { ODCONBbits.ODCB1 = 1; } while(0)
#define channel_ANB1_SetAnalogMode()      do { ANSELBbits.ANSELB1 = 1; } while(0)
#define channel_ANB1_SetDigitalMode()     do { ANSELBbits.ANSELB1 = 0; } while(0)

// get/set RB2 procedures
#define RB2_SetHigh()            do { LATBbits.LATB2 = 1; } while(0)
#define RB2_SetLow()             do { LATBbits.LATB2 = 0; } while(0)
#define RB2_Toggle()             do { LATBbits.LATB2 = ~LATBbits.LATB2; } while(0)
#define RB2_GetValue()              PORTBbits.RB2
#define RB2_SetDigitalInput()    do { TRISBbits.TRISB2 = 1; } while(0)
#define RB2_SetDigitalOutput()   do { TRISBbits.TRISB2 = 0; } while(0)
#define RB2_SetPullup()             do { WPUBbits.WPUB2 = 1; } while(0)
#define RB2_ResetPullup()           do { WPUBbits.WPUB2 = 0; } while(0)
#define RB2_SetAnalogMode()         do { ANSELBbits.ANSELB2 = 1; } while(0)
#define RB2_SetDigitalMode()        do { ANSELBbits.ANSELB2 = 0; } while(0)

// get/set RB3 procedures
#define RB3_SetHigh()            do { LATBbits.LATB3 = 1; } while(0)
#define RB3_SetLow()             do { LATBbits.LATB3 = 0; } while(0)
#define RB3_Toggle()             do { LATBbits.LATB3 = ~LATBbits.LATB3; } while(0)
#define RB3_GetValue()              PORTBbits.RB3
#define RB3_SetDigitalInput()    do { TRISBbits.TRISB3 = 1; } while(0)
#define RB3_SetDigitalOutput()   do { TRISBbits.TRISB3 = 0; } while(0)
#define RB3_SetPullup()             do { WPUBbits.WPUB3 = 1; } while(0)
#define RB3_ResetPullup()           do { WPUBbits.WPUB3 = 0; } while(0)
#define RB3_SetAnalogMode()         do { ANSELBbits.ANSELB3 = 1; } while(0)
#define RB3_SetDigitalMode()        do { ANSELBbits.ANSELB3 = 0; } while(0)

// get/set RB4 procedures
#define RB4_SetHigh()            do { LATBbits.LATB4 = 1; } while(0)
#define RB4_SetLow()             do { LATBbits.LATB4 = 0; } while(0)
#define RB4_Toggle()             do { LATBbits.LATB4 = ~LATBbits.LATB4; } while(0)
#define RB4_GetValue()              PORTBbits.RB4
#define RB4_SetDigitalInput()    do { TRISBbits.TRISB4 = 1; } while(0)
#define RB4_SetDigitalOutput()   do { TRISBbits.TRISB4 = 0; } while(0)
#define RB4_SetPullup()             do { WPUBbits.WPUB4 = 1; } while(0)
#define RB4_ResetPullup()           do { WPUBbits.WPUB4 = 0; } while(0)
#define RB4_SetAnalogMode()         do { ANSELBbits.ANSELB4 = 1; } while(0)
#define RB4_SetDigitalMode()        do { ANSELBbits.ANSELB4 = 0; } while(0)

// get/set RB5 procedures
#define RB5_SetHigh()            do { LATBbits.LATB5 = 1; } while(0)
#define RB5_SetLow()             do { LATBbits.LATB5 = 0; } while(0)
#define RB5_Toggle()             do { LATBbits.LATB5 = ~LATBbits.LATB5; } while(0)
#define RB5_GetValue()              PORTBbits.RB5
#define RB5_SetDigitalInput()    do { TRISBbits.TRISB5 = 1; } while(0)
#define RB5_SetDigitalOutput()   do { TRISBbits.TRISB5 = 0; } while(0)
#define RB5_SetPullup()             do { WPUBbits.WPUB5 = 1; } while(0)
#define RB5_ResetPullup()           do { WPUBbits.WPUB5 = 0; } while(0)
#define RB5_SetAnalogMode()         do { ANSELBbits.ANSELB5 = 1; } while(0)
#define RB5_SetDigitalMode()        do { ANSELBbits.ANSELB5 = 0; } while(0)
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

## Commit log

2023-02-17 add kicad
    [gpsdo-controller-B_Cu.gbr, gpsdo-controller-B_Mask.gbr, gpsdo-controller-B_Paste.gbr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]
2023-02-17 add schematic
2023-02-26 fix communication with Venus gps
    [gps.c, main.c]
2023-03-12 various code cleanups fix 3 hour storage of status
    [main.c]
2023-04-05 Fix commands to set gps to 115200 baud
    [gps.c, main.c]
2023-04-28 Add error (checksum) checking of gps messages
    [gps.c, main.c]
2024-10-13 improve error checking of gps serial data
    [gps.c, main.c]
